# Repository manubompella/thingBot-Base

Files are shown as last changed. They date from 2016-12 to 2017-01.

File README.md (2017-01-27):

# thingBot-Base

thingBot-Base is a universal baseboard designed to program all the thingBot family of devices and can be used 
for peripheral/sensor interfacing as well. Once the thingBots are programmed, Bots can be added to your existing projects
without any worries. 

## thingBot-Base v1.0 Features

  * [XBee Compatible Socket](https://www.sparkfun.com/datasheets/Wireless/Zigbee/XBee-Dimensional.pdf)
  * External 2.54mm header for easier connection to peripherals
  * c-JTAG (10 pin Cortex-M connector) for JTAG debugging the TARGET Bot
  * USB Micro connector (for programming and powering)
  * CP2102 USB to UART Bridge
  * Dual power supply (USB + Li-ion)
  
## thingBot-Base v2.0 Features
  
  * [XBee Compatible Socket](https://www.sparkfun.com/datasheets/Wireless/Zigbee/XBee-Dimensional.pdf)
  * External 2.54mm header for easier connection to peripherals
  * c-JTAG (10 pin Cortex-M connector) for JTAG debugging the TARGET Bot
  * USB Micro connector (for programming and powering)
  * CP2102 USB to UART Bridge
  * Ethernet controller for developing edge-router application
  * Dual power supply with battery charging support
  
## Getting Started

  * Place any thingBot on the XBee Socket as mentioned on the base
  * Connect micro USB cable to the base and your computer
  * Go into the download mode as mentioned in the desired thingBot manual
  * Start code upload and enjoy!!!
  
## Maintainers

The thingBot-Base is maintained by thingTronics Innovations.

Main contributor:
 * Manohar Bompella @<manohar.bompella@thingtronics.com>
 * Vishnu Sherikar @<vishnu.sherikar@thingtronics.com>
 * Lovelesh Patel @<lovelesh.patel@thingtronics.com>

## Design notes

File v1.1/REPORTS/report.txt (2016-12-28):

Plot file 'C:\Users\bomma\Documents\GitHub\thingBot-Base\v1.0\GERBER\thingBot-Base_v1P0-F.Cu.gbr' created.
Plot file 'C:\Users\bomma\Documents\GitHub\thingBot-Base\v1.0\GERBER\thingBot-Base_v1P0-B.Cu.gbr' created.
Plot file 'C:\Users\bomma\Documents\GitHub\thingBot-Base\v1.0\GERBER\thingBot-Base_v1P0-B.Paste.gbr' created.
Plot file 'C:\Users\bomma\Documents\GitHub\thingBot-Base\v1.0\GERBER\thingBot-Base_v1P0-F.Paste.gbr' created.
Plot file 'C:\Users\bomma\Documents\GitHub\thingBot-Base\v1.0\GERBER\thingBot-Base_v1P0-B.SilkS.gbr' created.
Plot file 'C:\Users\bomma\Documents\GitHub\thingBot-Base\v1.0\GERBER\thingBot-Base_v1P0-F.SilkS.gbr' created.
Plot file 'C:\Users\bomma\Documents\GitHub\thingBot-Base\v1.0\GERBER\thingBot-Base_v1P0-B.Mask.gbr' created.
Plot file 'C:\Users\bomma\Documents\GitHub\thingBot-Base\v1.0\GERBER\thingBot-Base_v1P0-F.Mask.gbr' created.
Plot file 'C:\Users\bomma\Documents\GitHub\thingBot-Base\v1.0\GERBER\thingBot-Base_v1P0-Dwgs.User.gbr' created.
Plot file 'C:\Users\bomma\Documents\GitHub\thingBot-Base\v1.0\GERBER\thingBot-Base_v1P0-Edge.Cuts.gbr' created.
Plot file 'C:\Users\bomma\Documents\GitHub\thingBot-Base\v1.0\GERBER\thingBot-Base_v1P0-Margin.gbr' created.
Plot file 'C:\Users\bomma\Documents\GitHub\thingBot-Base\v1.0\GERBER\thingBot-Base_v1P0-B.Fab.gbr' created.
Plot file 'C:\Users\bomma\Documents\GitHub\thingBot-Base\v1.0\GERBER\thingBot-Base_v1P0-F.Fab.gbr' created.

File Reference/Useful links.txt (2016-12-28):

https://gr33nonline.wordpress.com/2016/10/28/usb-serial-interfaces/#more-7186
http://www.sunrom.com/p/microusb-connector-with-through-hole-support-legs

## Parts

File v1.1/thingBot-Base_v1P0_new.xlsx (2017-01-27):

Reference | Quantity | Value | DESC
C1 | 1 | 0.1uF | Multilayer Ceramic Capacitors MLCC - SMD/SMT 10K pF 16V 10%
C3 C4 C2 | 3 | 1uF | Multilayer Ceramic Capacitors MLCC - SMD/SMT 10K pF 16V 10%
C5 C6 | 2 | 47pF | Multilayer Ceramic Capacitors MLCC - SMD/SMT 10K pF 16V 10%
D1 D2 | 2 | YELLOW | Yellow led for Data Receiving indication
D3 | 1 | POWER | GREEN led for power indication
P1 | 1 | Micro_usb_B | Micro Usb Series B Receptacle Trough Hole
P2 | 1 | BATT_CONN | JST_XH_S02B-XH-A_02x2.54mm_Angled
P3 | 1 | XBEE_CONN_LEFT | 1X10 2.54 mm Male TH
P4 P5 | 2 | CONN_01X02 | 1X10 2.54 mm Male TH
P6 | 1 | JTAG | Pin_Header_Straight_SMT_02x05_1.27mm_Pitch male
P7 | 1 | XBEE | Xbee Socket with 2x05 SMT Female 1.27mm_Pitch Header
P8 | 1 | XBEE_CONN_RIGHT | 1X10 2.54 mm Male TH
R1 R2 R3 | 3 | 1K | Current Sense Resistors - SMD 0805 0.002ohm 1% AEC-Q200
R4 R5 | 2 | 27E | Current Sense Resistors - SMD 0805 0.002ohm 1% AEC-Q200
SW1 | 1 | ON/OFF_Switch | Mini ON/OFF type switch rated at 50VDC@300mA
U2 | 1 | CP2102 | Single-Chip USB to UART Data Transfer
U3 | 1 | LP5907_LDO_250mA | SOT-23-5 250mA_250mV-dropout
U4 | 1 | PROBE | 1x2 2.54 mm Header with Jumper

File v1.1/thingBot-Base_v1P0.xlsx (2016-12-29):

thingBot-Base
BILL OF MATERIALS
Item | Quantity | Reference | Value | DESC | MFG_NAME | MPN | Footprint | PCB Package | 1 | 100 | 500 | 1000 |  | 10 PCB | 100 PCB | 1000 PCB | Purchased cost for 100
1 | 1 | C1 | 0.1uF | Multilayer Ceramic Capacitors MLCC - SMD/SMT 0805 1uF 10volts X7R 10% | Vishay / Vitramon (http://www.mouser.in/vitramon/) | VJ0805Y105KXQTW1BC | Capacitors_SMD:C_0805_HandSoldering | 805 | 3.5 | 2.1 | 2.1 | 2.1 |  | 3.5 | 2.1 | 2.1 | 1
2 | 3 | C2 C3 C4 | 1uF | Multilayer Ceramic Capacitors MLCC - SMD/SMT 0805 1uF 10volts X7R 10% | Vishay / Vitramon (http://www.mouser.in/vitramon/) | VJ0805Y105KXQTW1BC | Capacitors_SMD:C_0805_HandSoldering | 805 | 3.5 | 2.1 | 2.1 | 2.1 |  | 10.5 | 6.3 | 6.3 | 0.9
 | 2 | C5 C6 | 47pF | Multilayer Ceramic Capacitors MLCC - SMD/SMT 0805 1uF 10volts X7R 10% | Vishay / Vitramon (http://www.mouser.in/vitramon/) | VJ0805Y105KXQTW1BC | Capacitors_SMD:C_0805_HandSoldering | 805 | 3.5 | 2.1 | 2.1 | 2.1 |  | 7 | 4.2 | 4.2 | 0.8
4 | 2 | D1 D2 | YELLOW LED | Yellow led for Data Receiving/Transmiting indication | Kingbright | APT2012YC (http://www.mouser.in/ProductDetail/Kingbright/APT2012YC/?qs=sGAEpiMZZMseGfSY3csMkeytxqHAv00AKvOaAyVdWVo%3d) | LEDs:LED_0805 | 805 | 9.1 | 4.76 | 4.76 | 4.55 |  | 18.2 | 9.52 | 9.1 | 1.4
5 | 1 | D3 | POWER LED | GREEN led for power indication | Kingbright | APT2012SGC (http://www.mouser.in/ProductDetail/Kingbright/APT2012SGC/?qs=sGAEpiMZZMseGfSY3csMkeytxqHAv00AGb4ncJXLQok%3d) | LEDs:LED_0805 | 805 | 9.8 | 4.76 | 4.76 | 4.55 |  | 9.8 | 4.76 | 4.55 | 1.2
6 | 1 | P1 | MICRO_USB | Micro Usb Series B Receptacle Trough Hole | Hirose Connector | ZX62D-B-5PA8(30) | Connect:USB_Micro-B |  | 49 | 32.34 | 30.8 | 25.41 |  | 49 | 32.34 | 25.41 | 20
7 | 1 | P2 | BATT_CONN | JST_XH_S02B-XH-A_02x2.54mm_Angled | ******* | 09749 ROHS (https://www.sparkfun.com/static/rohs/) | Connectors_JST:JST_XH_S02B-XH-A_02x2.50mm_Angled |  | 10 | 5 | 5 | 5 |  | 10 | 5 | 5 | 1
8 | 1 | P3 | XBEE_CONN_LEFT | 1X10 2.54 mm Male TH | Worth Elektronic | 61300211121 | Pin_Headers:Pin_Header_Straight_1x10 |  | 8.4 | 7.42 | 6.3 | 6.23 |  | 8.4 | 7.42 | 6.23 | 1.5
9 | 1 | P4 | JTAG | Pin_Header_Straight_SMT_02x05_1.27mm_Pitch male | Amphenol FCI (http://www.mouser.in/fci/) | 20021121-00008C1LF | pin_header:Pin_Header_Straight_SMT_02x05_1.27mm_Pitch |  | 42.7 | 31.08 | 27.02 | 22.26 |  | 42.7 | 31.08 | 22.26 | 7
10 | 1 | P5 | XBEE(DNM) | Xbee Socket with 2x05 SMT Female 1.27mm_Pitch Header | ***** | ***** | Xbee:XBee_Plug |  |  |  |  |  |  | 0 | 0 | 0 | 0
11 | 1 | P6 | XBEE_CONN_RIGHT | 1X10 2.54 mm Male TH | Worth Elekronik | 61300211121 | Pin_Headers:Pin_Header_Straight_1x10 |  | 8.4 | 7.42 | 6.3 | 6.23 |  | 8.4 | 7.42 | 6.23 | 1.5
 | 2 | R4 R5 | 27E | Current Sense Resistors - SMD 0805 0.002ohm 1% AEC-Q200 | Murata Electronics (http://www.mouser.in/murataelectronics/) | BLM21AG102SN1D | Resistors_SMD:R_0805_HandSoldering | 805 | 7.7 | 2.8 | 2.8 | 2.59 |  | 15.4 | 5.6 | 5.6 | 1.5
12 | 3 | R1 R2 R3 | 1K | Current Sense Resistors - SMD 0805 0.002ohm 1% AEC-Q200 | Murata Electronics (http://www.mouser.in/murataelectronics/) | BLM21AG102SN1D | Resistors_SMD:R_0805_HandSoldering | 805 | 7.7 | 2.8 | 2.8 | 2.59 |  | 23.1 | 8.4 | 7.77 | 1
13 | 1 | SW1 | ON/OFF_Switch | Mini ON/OFF type switch rated at 50VDC@300mA | sunrom | 4273 | Buttons_Switches_SMD:SW_SPDT_PCM12 |  | 10 | 8 | 8 | 8 |  | 10 | 8 | 8 | 12
15 | 1 | U2 | CP2102 | Single-Chip USB to UART Data Transfer | Silicon Labs | CP2102-GM | Housings_DFN_QFN:QFN-28-1EP_5x5mm_Pitch0.5mm | QFN-28 | 192.5 | 178.5 | 168.7 | 162.4 |  | 192.5 | 178.5 | 162.4 | 85
16 | 1 | U3 | LP5907_LDO_250mA | SOT-23-5 250mA_250mV-dropout | Texas Instruments | LP5907MFX-3.3/NOPB (http://www.mouser.in/ProductDetail/Texas-Instruments/LP5907MFX-33-NOPB/?qs=sGAEpiMZZMtxga3Frp99ssdbdmlAwb6R) | TO_SOT_Packages_SMD:SOT-23-5 | SOT-23-5 | 39.2 | 25.48 | 19.39 | 11.06 |  | 39.2 | 25.48 | 11.06 | 25.48
17 | 1 | U4 | PROBE | 1x2 2.54 mm Header with Jumper | Worth Elektronic | 61300211121 | Pin_Headers:Pin_Header_Straight_2x01 |  | 8.4 | 7.42 | 6.3 | 6.23 |  | 8.4 | 7.42 | 6.23 | 1
18 | 2 | P7 P8 | Xbee_module_headers | 1x10 2.0mm Female Header TH | Harwin | M22-2510205 |  |  | 13.3 | 6.37 | 6.37 | 5.6 |  | 26.6 | 12.74 | 11.2 | 7
19 | 1 | P9 | JTAG Female | Pin_Header_Straight_SMT_02x05_1.27mm_Pitch female | Harwin | M50-3103345 |  |  | 42.7 | 31.08 | 27.02 | 22.26 |  | 42.7 | 31.08 | 22.26 | 7
 |  |  |  |  |  |  |  |  |  |  |  |  | TOTAL | 525.4 | 387.36 | 325.9 | 176.28

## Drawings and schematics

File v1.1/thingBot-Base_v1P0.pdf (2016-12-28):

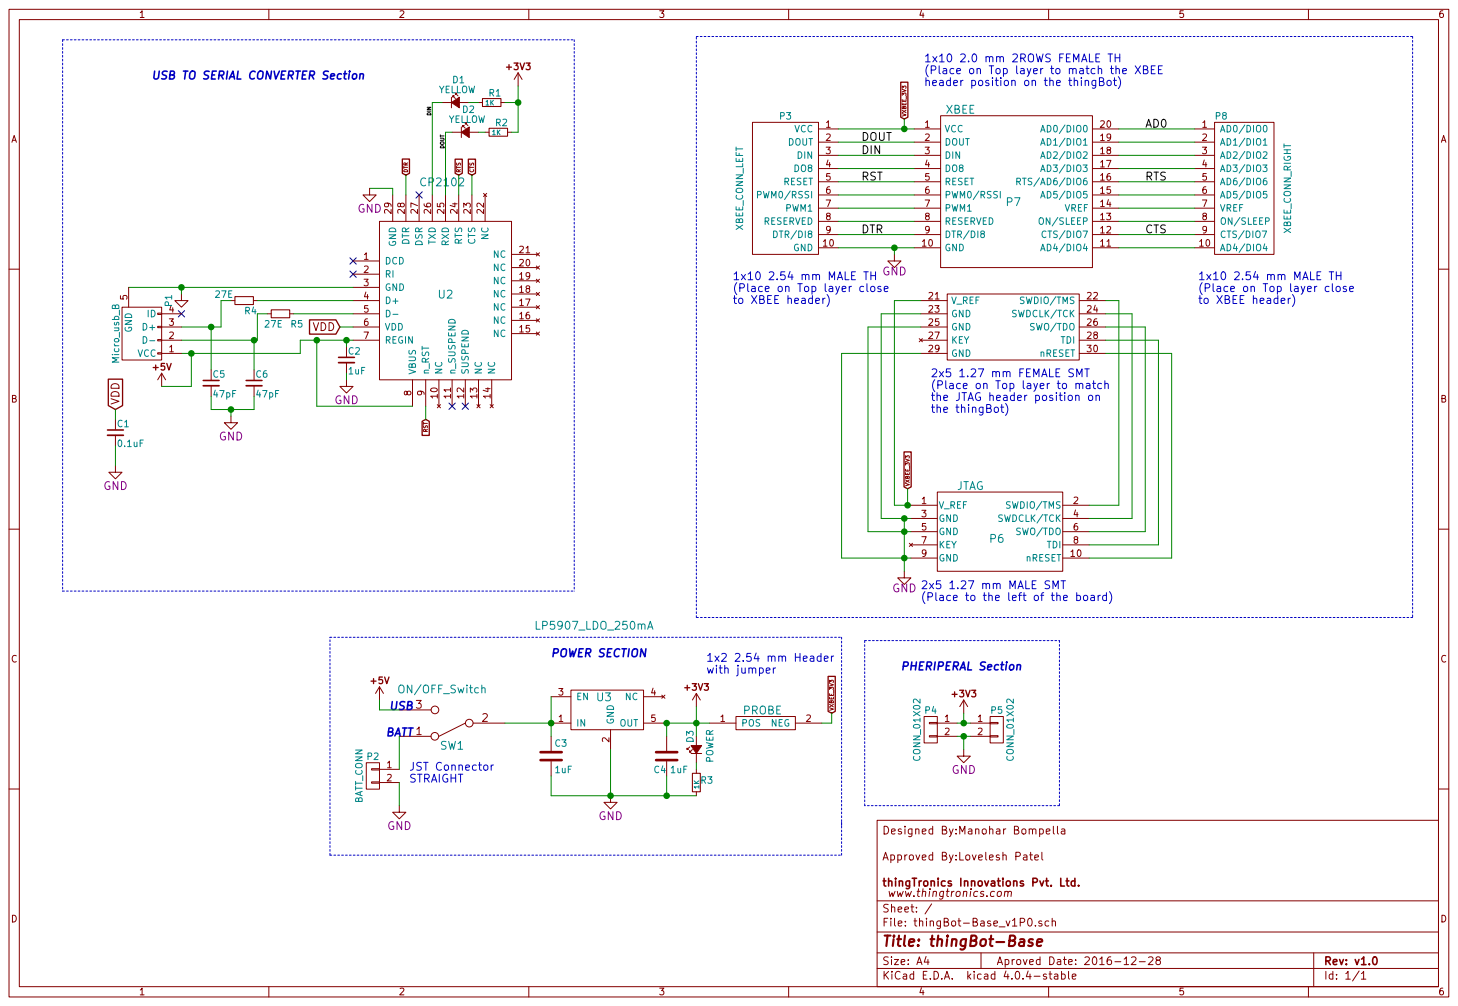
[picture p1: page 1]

1x10 2.0 mm 2ROWS FEMALE TH
(Place on Top layer to match the XBEE
header position on the thingBot)

USB TO SERIAL CONVERTER Section

to XBEE header) DOUT DIN GND

9 NC 10 NC 20 n_SUSPEND 11 NC 21 SUSPEND 12 NC 22 NC 13 CTS 23 NC 14 RTS 24 NC 15 RXD 25 NC 16 TXD 26 NC 17 DSR 27 NC 18 DTR 28 NC 19 GND 29 U2 CP2102

2x5 1.27 mm FEMALE SMT
(Place on Top layer to match
the JTAG header position on
the thingBot)

2x5 1.27 mm MALE SMT
GND
(Place to the left of the board)

Designed By:Manohar Bompella

Approved By:Lovelesh Patel

thingTronics Innovations Pvt. Ltd.
File: thingBot-Base_v1P0.sch Sheet: / www.thingtronics.com

Id: 1/1 Title: thingBot-Base

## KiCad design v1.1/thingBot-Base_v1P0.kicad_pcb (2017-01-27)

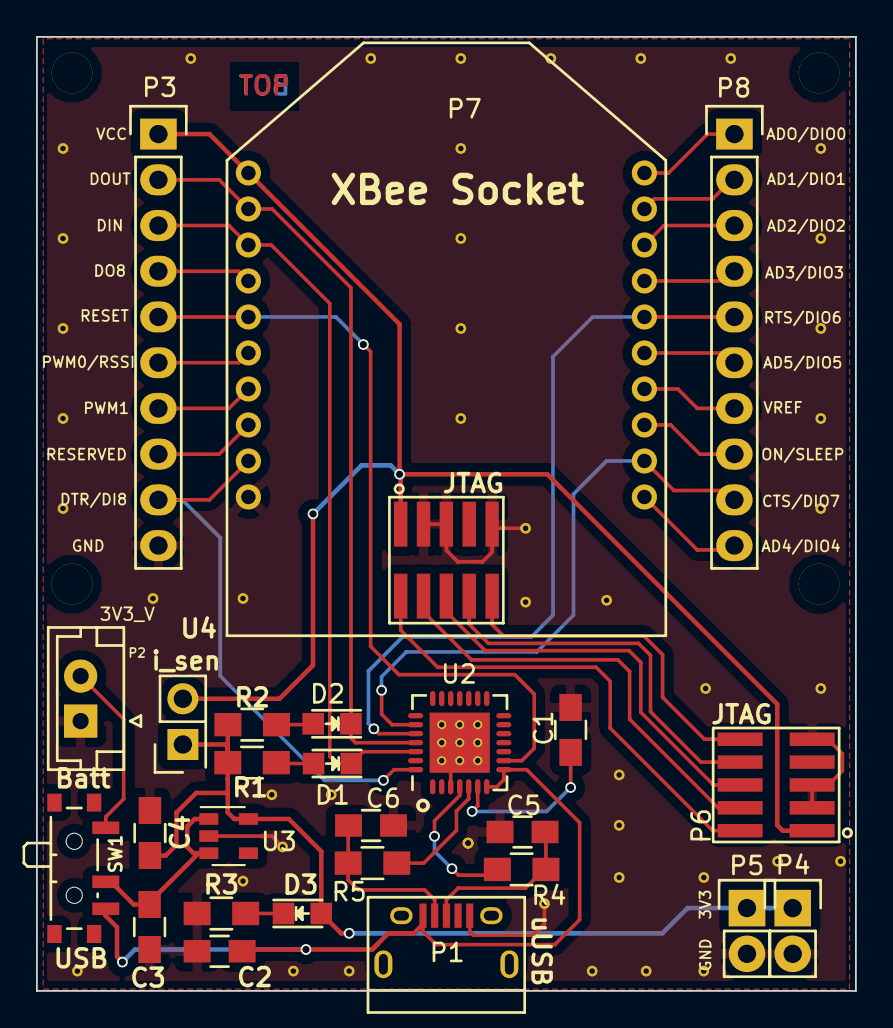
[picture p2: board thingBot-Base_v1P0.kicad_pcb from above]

Board: 2 copper layers, 45.5 x 53.0 mm, 26 parts (0 on the bottom side), 37 nets.

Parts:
C1: 0.1uF; C_0805_HandSoldering
C2, C3, C4: 1uF; C_0805_HandSoldering
C5, C6: 47pF; C_0805_HandSoldering
D1, D2: YELLOW; LED_0805
D3: POWER; LED_0805
P1: Micro_usb_B; USB_Micro-B
P2: BATT_CONN; JST_EH_B02B-EH-A_02x2.50mm_Straight
P3: XBEE_CONN_LEFT; Pin_Header_Straight_1x10
P4, P5: CONN_01X02; Pin_Header_Straight_1x02
P6: JTAG; Pin_Header_Straight_SMT_02x05_1.27mm_Pitch
P7: XBEE; XBee_Plug
P8: XBEE_CONN_RIGHT; Pin_Header_Straight_1x10
R1, R2, R3: 1K; R_0805_HandSoldering
R4, R5: 27E; R_0805_HandSoldering
SW1: ON/OFF_Switch; SW_SPDT_PCM12
U2: CP2102; QFN-28-1EP_5x5mm_Pitch0.5mm
U3: LP5907_LDO_250mA; SOT-23-5
U4: PROBE; Pin_Header_Straight_2x01

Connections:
+3V3: C4.1, D3.2, P4.1, P5.1, R1.1, R2.1, U3.5, U4.1
+5V: C2.1, P1.1, SW1.3, U2.7, U2.8
/AD0: P7.20, P8.1
/DIN: D1.1, P3.3, P7.3, U2.26
/DOUT: D2.1, P3.2, P7.2, U2.25
CTS: P7.12, P8.9, U2.23
DTR: P3.9, P7.9, U2.28
GND: C1.2, C2.2, C3.2, C4.2, C5.2, C6.2, P1.5, P2.1, P3.10, P4.2, P5.2, P6.3, P6.5, P6.9, P7.10, P7.23, P7.25, P7.29, R3.2, U2.3, U2.29, U3.2
unnamed: C3.1, SW1.2, U3.1, U3.3
unnamed: C5.1, P1.3, R4.2
unnamed: C6.1, P1.2, R5.2
unnamed: D1.2, R1.2
unnamed: D2.2, R2.2
unnamed: D3.1, R3.1
unnamed: P2.2, SW1.1
unnamed: P3.4, P7.4
unnamed: P3.6, P7.6
unnamed: P3.7, P7.7
unnamed: P3.8, P7.8
unnamed: P6.2, P7.22
unnamed: P6.4, P7.24
unnamed: P6.6, P7.26
unnamed: P6.8, P7.28
unnamed: P6.10, P7.30
unnamed: P7.11, P8.10
unnamed: P7.13, P8.8
unnamed: P7.14, P8.7
unnamed: P7.15, P8.6
unnamed: P7.17, P8.4
unnamed: P7.18, P8.3
unnamed: P7.19, P8.2
unnamed: R4.1, U2.4
unnamed: R5.1, U2.5
RST: P3.5, P7.5, U2.9
RTS: P7.16, P8.5, U2.24
VDD: C1.1, U2.6
VXBEE_3V3: P3.1, P6.1, P7.1, P7.21, U4.2

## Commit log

2016-11-24 added directories for PCB schematic design, refrence nad libraries
2016-11-24 added openbase schematic; added sch and project file
    [thingBot-Base_v1P0.kicad_pcb, thingBot-Base_v1P0.sch]
2016-11-27 Complete Schematic Added
    Added Power Section, Usb to Serial Converter Section.
    SPDT switch added for powering the module through Battery and micro USB.
    JTAG Headers included.
    On Board Power indication Led and 3.3v fixed voltage Regulator Added.
    [thingBot-Base_v1P0.sch]
2016-11-27 Modified README (#4)
    * edited README with 2 versions of base
    * added battery support
2016-11-27 Libraries Added and some changes made in Schematic
    CP2102 ,probe, AMS117 Libraries added,
    C4,C5 Capacitors Added JTAG gnds connected to Common ground.
2016-11-27 changed README; removed unrequired datasheet
    [thingBot-Base_v1P0.sch]
2016-12-26 Reference files ,bom xl,complete layout added
    following things added
    -reference files
    -complete layout
    -in schematic removed esd protection vbus053a, and added RC circuit
    -lm1117 replaced with lp5907
    -BOM xl sheet added
    [thingBot-Base_v1P0.kicad_pcb, thingBot-Base_v1P0.sch, thingBot-Base_v1P0.xlsx]
2016-12-28 final Layout and GERBER creation done
    [thingBot-Base_v1P0-B.Cu.gbr, thingBot-Base_v1P0-B.Fab.gbr, thingBot-Base_v1P0-B.Mask.gbr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]
2016-12-29 BOM updated
    [thingBot-Base_v1P0.xlsx]
2016-12-30 version of board added in silkscreen
    [thingBot-Base_v1P0-B.Cu.gbr, thingBot-Base_v1P0-B.Fab.gbr, thingBot-Base_v1P0-B.Mask.gbr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]
2017-01-27 thingBot-Base v1.1 all files added
    in v1.1 these thing Added
    - JST connector pins changed
    - 1x2 2.54mm headers alighned properly
    [thingBot-Base_v1P0-B.Cu.gbr, thingBot-Base_v1P0-B.Fab.gbr, thingBot-Base_v1P0-B.Mask.gbr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]
